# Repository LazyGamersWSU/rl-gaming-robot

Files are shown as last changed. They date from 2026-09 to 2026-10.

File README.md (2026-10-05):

# RL Gaming Robot

The RL Gaming Robot is a senior design project focused on developing a Reinforcement Learning system that learns to play games through repeated attempts and applies its learned behavior to a game to ultimately improve its score.

The current target game is Tetris. The long-term goal is for the RL agent to make gameplay decisions and output controller commands that are translated into physical actions pressed on a controller by a robotic system.

This repository contains the software and hardware elements used to create the project.

## Repository Structure

```text
RL-Gaming-Robot/

├── hardware/
│   ├── electronics/
│   ├── experiments/
│   ├── firmware/
│   ├── mechanical/
│   └── photos/
│ 
├── software/
│   ├── requirements/
│   ├── environment/
│   ├── agent/
│   └── test_cases/
│
└── README.md
```

## Hardware

The `hardware` directory contains the mechanical and electronic development files for the RL Gaming Robot.

This includes:

* Actuator experiments and testing
* CAD models and mechanical designs
* Controller mounting and interaction components
* Production hardware designs
* Hardware documentation and validation

See the [hardware README](hardware/README.md) for additional information.

## Software

The `software` directory contains the software required to develop and operate the RL system.

This includes:

* Python environment and dependency requirements
* Game environment code
* Reinforcement Learning agent code
* Software test cases

The software is responsible for interacting with the game environment, training and executing the RL agent, and producing controller actions for the hardware system.

See the [software README](software/README.md) for additional information.

## System Overview

The intended system operates as a feedback loop:

```text
┌─────────────────┐
│ Game Environment│
└────────┬────────┘
         │
         │ Game State
         ▼
┌─────────────────┐
│    RL Agent     │
└────────┬────────┘
         │
         │ Controller Action
         ▼
┌─────────────────┐
│ Robot Controller│
└────────┬────────┘
         │
         │ Physical Command
         ▼
┌─────────────────┐
│  Robotic System  │
└────────┬────────┘
         │
         │ Button Press
         ▼
┌─────────────────┐
│  NES Controller │
└────────┬────────┘
         │
         └──────────────► Game
```

The game produces a new state after each action, allowing the RL agent to continually evaluate the game and select its next action.

## Testing

Testing is an integral part of the project and is performed throughout both software and hardware development.

Software testing focuses on:

* Game-state processing
* RL agent behavior
* Action generation
* Software component integration
* Model performance and repeatability

Hardware testing focuses on:

* Actuator performance
* Button press accuracy
* Timing and reliability
* Mechanical positioning
* Hardware/software integration

Test cases are maintained within the appropriate software and hardware directories.

## Development Philosophy

The project is organized around **experimentation, validation, and integration**.

Development follows these general principles:

1. **Experiment** — Develop and test individual concepts and components.
2. **Validate** — Verify that components meet their intended requirements.
3. **Integrate** — Combine validated software and hardware components.
4. **Test** — Evaluate the complete system and identify integration issues.
5. **Iterate** — Use test results to improve the system.

Experimental implementations should be validated before being incorporated into the production system.

## Project Goals

The primary goals of the RL Gaming Robot project are to:

* Develop an RL agent capable of improving its gameplay through repeated attempts.
* Create a software environment for training and evaluating the agent.
* Develop a robotic system capable of physically interacting with a gaming controller.
* Establish reliable communication between the software and hardware systems.
* Test the performance and reliability of the complete system.
* Demonstrate the transfer of learned behavior from the software environment to physical gameplay.

## Current Development Status

The project is being developed incrementally, beginning with the software RL environment and agent before progressing toward full hardware integration.

Major development stages include:

1. Software environment development
2. RL agent development and training
3. Software testing and performance evaluation
4. Hardware development and validation
5. Software/hardware integration
6. Full-system testing
7. Final NES Tetris demonstration

## Team Roles

### Trystan Donmoyer - Software Development Lead
- Leads development of the reinforcement learning software and agent
- Develops training, inference, and game interaction systems
- Maintains the software architecture and coordinates software-side implementation

### Sam Culp - Hardware Development
- Leads hardware design and implementation of the physical gaming robot
- Designs and assembles the PCB, power distribution, actuator system, and mechanical components
- Develops and integrates Arduino firmware for hardware control and communication with the software system

### Matthew Dynes-Winberry - Integration & Testing
- Integrates the software and hardware systems into a complete working platform
- Develops and manages system-level testing and validation
- Troubleshoots issues across hardware/software interfaces and verifies system reliability

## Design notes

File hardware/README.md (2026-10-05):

# Hardware

Hardware design, firmware, schematics, experiments, and documentation for the RL gaming robot.

## Directories

* [`electronics/`](electronics/) — Electrical system documentation, PCB design, power budget, and wiring diagrams.
* [`mechanical/`](mechanical/) — Mechanical design documentation and CAD files.
* [`firmware/`](firmware/) — Arduino firmware for the hardware control system.
* [`experiments/`](experiments/) — Hardware and controller experiments used during development.
* [`photos/`](photos/) — Miscellaneous hardware photos.

## System Overview

Hardware Block Diagram

For detailed electrical architecture and subsystem documentation, see [`electronics/`](electronics/).

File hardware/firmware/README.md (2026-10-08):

# Firmware

Arduino firmware for controlling the solenoid driver PCB and translating commands received over USB into physical controller inputs.
The current code content is a demonstration of what is to come.

## Planned Contents

- Arduino source code
- Pin assignments
- Serial communication protocol
- Solenoid control logic

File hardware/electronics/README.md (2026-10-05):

# Electronics

The electronics system controls and powers the solenoid actuators used to physically operate the game controller.

## Subsystems

- [PCB](pcb/) — Solenoid driver PCB design and fabrication files with revision history
- [Power](power/power_budget.md) — Battery and system power requirements
- [Wiring](wiring/) — Electrical wiring and connections (visual)

## Signal Path

Arduino → MOSFET driver → Solenoids

## Power Path

Battery → BMS → Power switch → Fuse  → Solenoid driver PCB → Solenoids

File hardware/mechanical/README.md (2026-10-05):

# Mechanical

Mechanical components for mounting and positioning the solenoid actuators over the game controller. A .f3d file is a proprietary Autodesk Fusion 360 archive that stores a complete parametric 3D CAD design. This means that these files must be opened with Autodesk Fusion 360.

## CAD Files

- `Actuator Plate.f3d` — Mounting plate for the solenoid actuators; actuators are friction fit into sleeves
- `Gantry Support.f3d` — Frame for holding the actuator plate above the cradle 
- `SNES Cradle.f3d` — Holds the game controller in place
- `Solenoid Sleeve.f3d` — Test sleeve for positioning and guiding the solenoid
- `snes_overlay.jpg` — Controller reference image used during CAD design

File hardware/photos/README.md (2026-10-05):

# Photos

Miscellaneous photos of the various hardware components throughout different stages of development.

## Contents

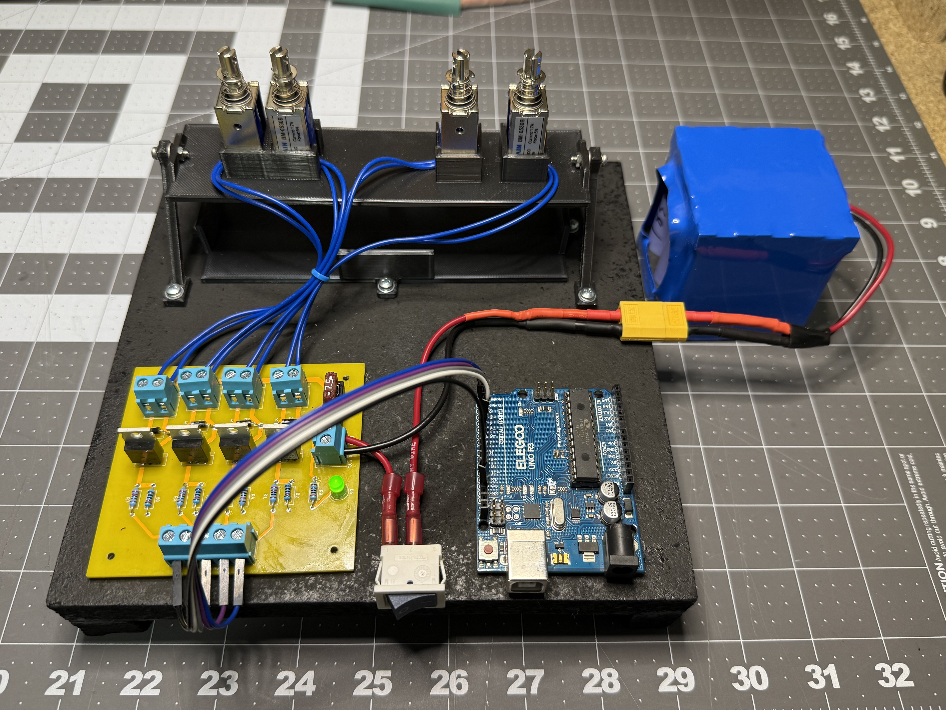
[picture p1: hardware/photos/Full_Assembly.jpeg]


Full assembly of all the components. The build plate is a piece of 1/2" particle board that was spray painted black. Bottom-left: circuit board. Bottom-right: Arduino. Top: controller cradle and actuator plate. Right: power supply and connector.

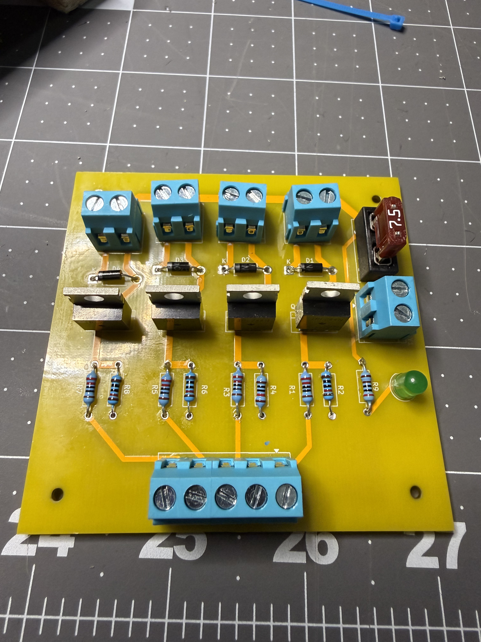
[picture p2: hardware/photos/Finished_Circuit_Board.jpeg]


Final circuit with all components soldered on. Corresponds with [revision v4.0](../electronics/pcb/PCB_REVISION_HISTORY.md). This board was designed by Sam Culp and manufactured by JLCPCB. The components were ordered from DigiKey. 

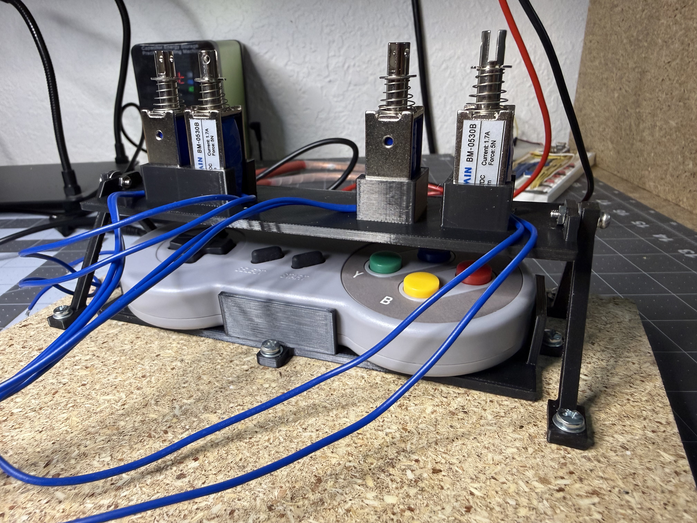
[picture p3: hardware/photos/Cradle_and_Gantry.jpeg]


SNES controller firmly held in its cradle. The gantry frame supports four solenoid linear actuators that are positioned right above the buttons.

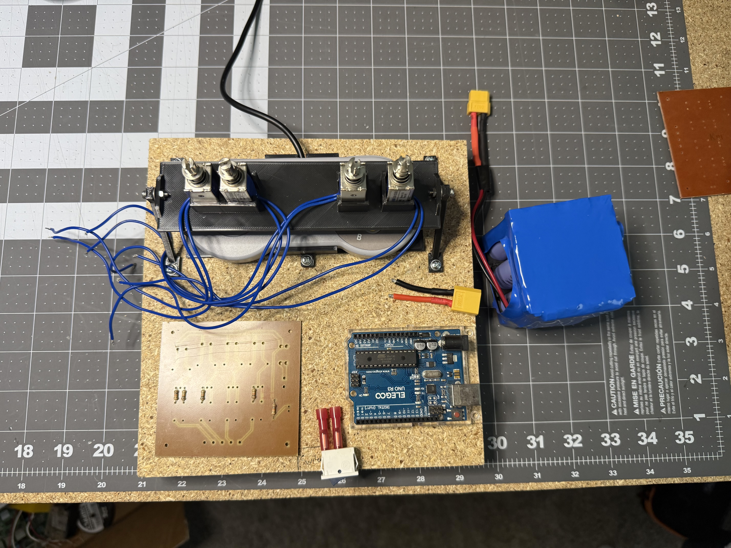
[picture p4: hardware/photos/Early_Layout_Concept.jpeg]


Initial concept for the layout of all the different components. This ended up closely resembling the final version.

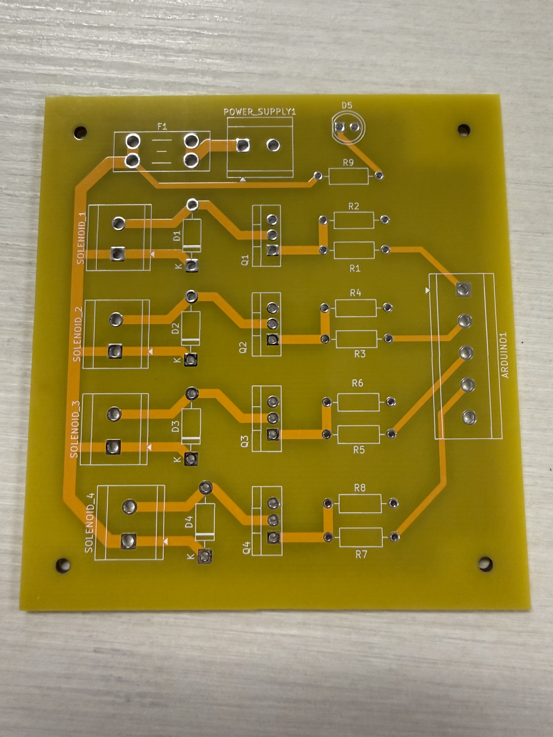
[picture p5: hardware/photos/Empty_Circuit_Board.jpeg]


Circuit board as it arrived from the manufacturer. Corresponds with [revision v4.0](../electronics/pcb/PCB_REVISION_HISTORY.md). Did not come with any components mounted, just through-holes.

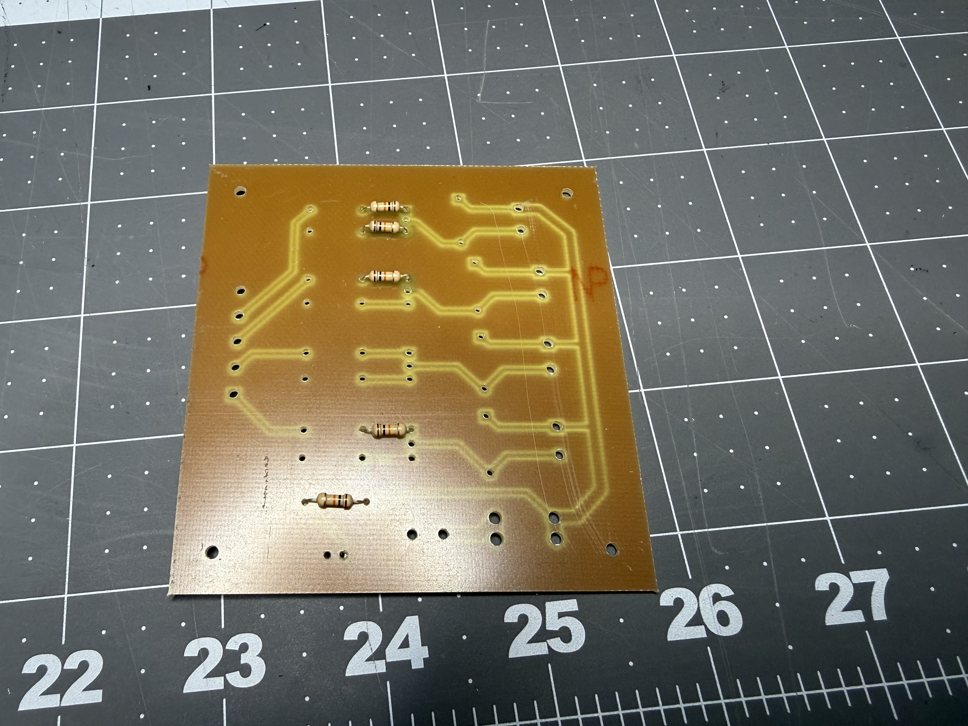
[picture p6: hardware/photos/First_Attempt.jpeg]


First attempt at manufacturing a circuit board. Corresponds with [revision v2.0](../electronics/pcb/PCB_REVISION_HISTORY.md). Sam Culp manufactured this in the Electronics Lab at Wichita State. This is a one-sided board made from a clad-copper PCB blank. Rather than laying down wires on a piece of material, the machine routed out the silhouette of each wire. Sam had to ensure proper sizing of the traces and annular rings to match the available drill bits.

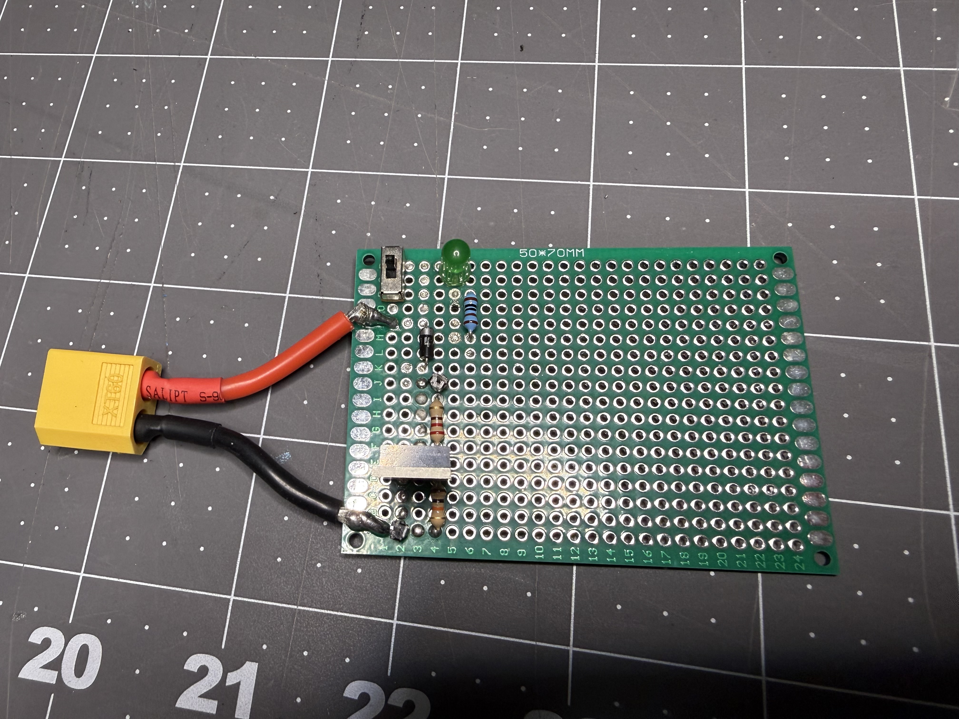
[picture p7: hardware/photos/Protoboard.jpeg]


Early proof-of-concept of the circuit soldered onto a protoboard. This board drives one actuator and takes one digital input from an arduino. The cables for the actuator were transplanted to the final build prior to this photo being taken.

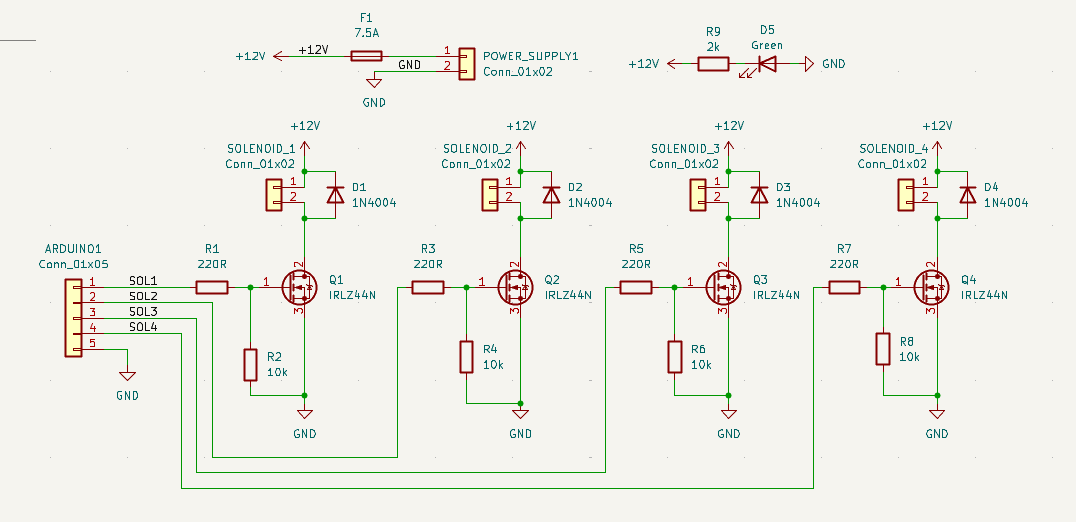
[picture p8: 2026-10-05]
hardware/electronics/wiring/schematic_diagram.png

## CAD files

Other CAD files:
hardware/mechanical/cad/Actuator Plate.f3d
hardware/mechanical/cad/Gantry Support.f3d
hardware/mechanical/cad/SNES Cradle.f3d

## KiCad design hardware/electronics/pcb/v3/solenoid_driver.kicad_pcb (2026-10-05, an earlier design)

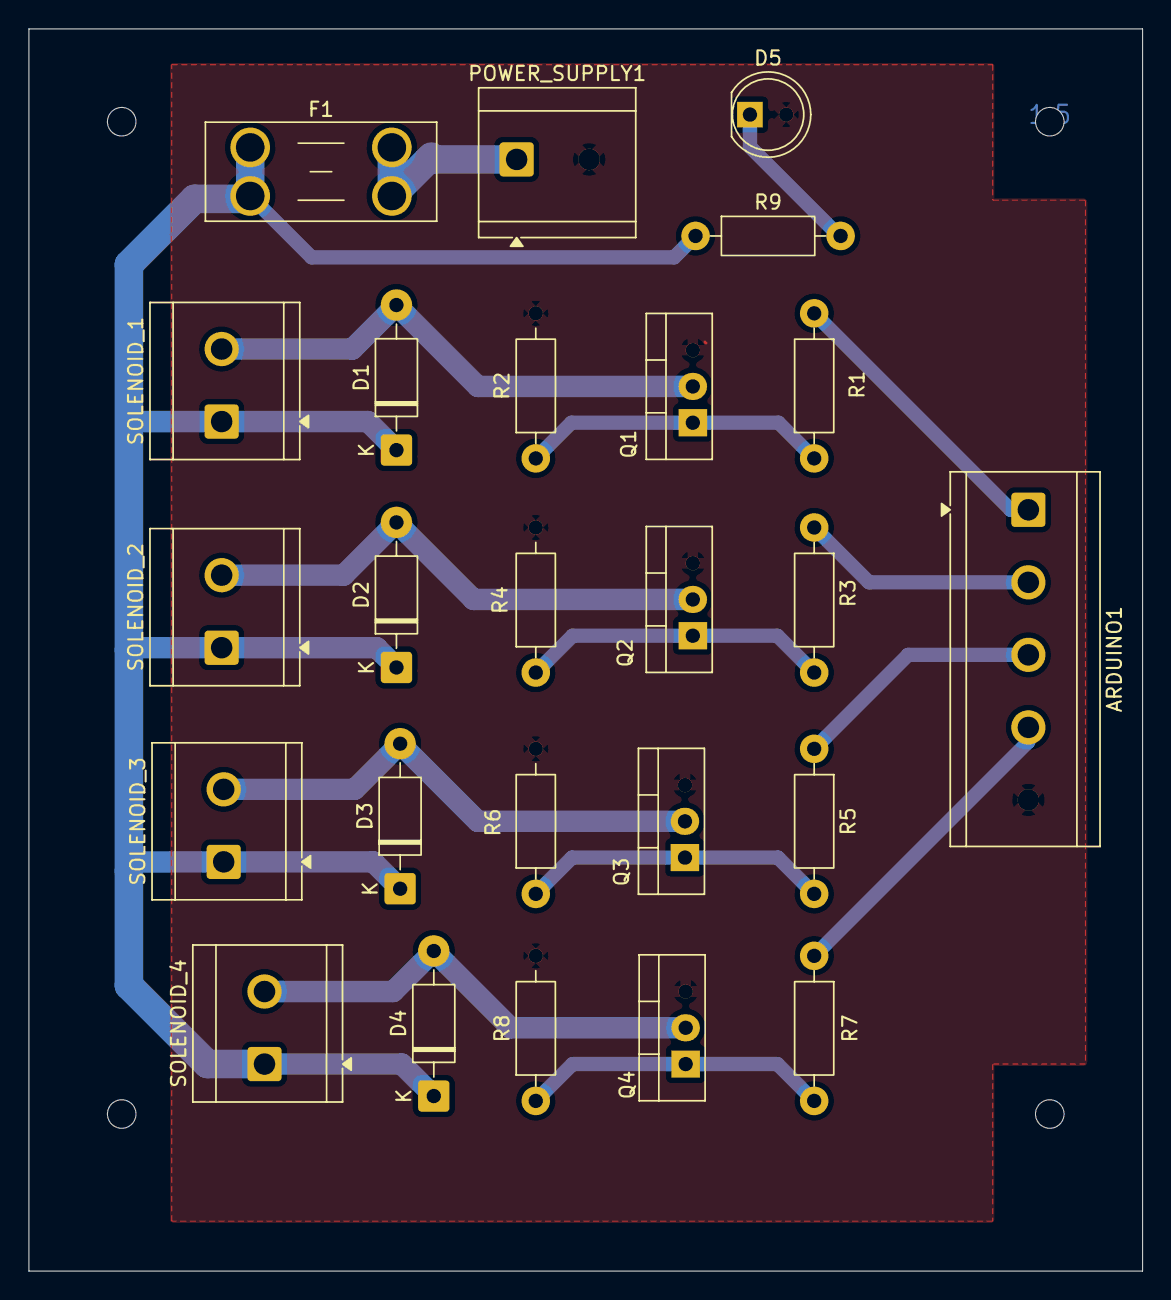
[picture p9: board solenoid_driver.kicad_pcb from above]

Board: 2 copper layers, 78.0 x 87.0 mm, 25 parts (0 on the bottom side), 16 nets.

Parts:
ARDUINO1: Conn_01x05; TerminalBlock_CUI_TB007-508-05_1x05_P5.08mm_Horizontal
D1, D2, D3, D4: 1N4004; D_DO-41_SOD81_P10.16mm_Horizontal
D5: Green; LED_D5.0mm
F1: 7.5A; Fuseholder_Blade_Mini_Keystone_3568
POWER_SUPPLY1: Conn_01x02; TerminalBlock_CUI_TB007-508-02_1x02_P5.08mm_Horizontal
Q1, Q2, Q3, Q4: IRLZ44N; TO-220-3_Vertical
R1, R3, R5, R7: 220R; R_Axial_DIN0207_L6.3mm_D2.5mm_P10.16mm_Horizontal
R2, R4, R6, R8: 10k; R_Axial_DIN0207_L6.3mm_D2.5mm_P10.16mm_Horizontal
R9: 1k; R_Axial_DIN0207_L6.3mm_D2.5mm_P10.16mm_Horizontal
SOLENOID_1, SOLENOID_2, SOLENOID_3, SOLENOID_4: Conn_01x02; TerminalBlock_CUI_TB007-508-02_1x02_P5.08mm_Horizontal

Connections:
+12V: D1.1 (K), D2.1 (K), D3.1 (K), D4.1 (K), F1.1, R9.1, SOLENOID_1.1, SOLENOID_2.1, SOLENOID_3.1, SOLENOID_4.1
/SOL1: ARDUINO1.1, R1.1
/SOL2: ARDUINO1.2, R3.1
/SOL3: ARDUINO1.3, R5.1
/SOL4: ARDUINO1.4, R7.1
GND: ARDUINO1.5, D5.2 (A), POWER_SUPPLY1.2, Q1.3 (S), Q2.3 (S), Q3.3 (S), Q4.3 (S), R2.2, R4.2, R6.2, R8.1
unnamed: D1.2 (A), Q1.2 (D), SOLENOID_1.2
unnamed: D2.2 (A), Q2.2 (D), SOLENOID_2.2
unnamed: D3.2 (A), Q3.2 (D), SOLENOID_3.2
unnamed: D4.2 (A), Q4.2 (D), SOLENOID_4.2
unnamed: D5.1 (K), R9.2
unnamed: F1.2, POWER_SUPPLY1.1
unnamed: Q1.1 (G), R1.2, R2.1
unnamed: Q2.1 (G), R3.2, R4.1
unnamed: Q3.1 (G), R5.2, R6.1
unnamed: Q4.1 (G), R7.2, R8.1

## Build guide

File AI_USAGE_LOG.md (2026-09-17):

# AI Usage & Verification Log

**Project Name:** RL Gaming Robot

---

## Overview & AI Usage Statement

### Overview & AI Usage Statement

AI tools were used throughout the project as a supplemental development resource for brainstorming, troubleshooting, and improving implementation approaches. AI-generated code and recommendations were reviewed, tested, and modified by the project team before being incorporated into the project. The team remains responsible for understanding and verifying all implemented solutions. AI was not treated as a replacement for independent research, engineering judgment, or testing.

### Responsible AI Usage

AI was used responsibly by treating its output as a starting point rather than an authoritative source. Generated code was reviewed for correctness, tested in the project environment, and modified when necessary. Project decisions and final implementations were verified by the team, and AI assistance was documented in this log to maintain transparency and accountability.

---

## Entry 1: Prototype 1 - SNES USB Controller Input Mapping Experiment

* **Date:** August 31, 2026  
* **Tool Used:** ChatGPT  
* **Associated Git Issue:** Test SNES USB controller input mapping  
* **Associated Feature Branch:** `controller-input-test`  

### Exact Prompt Submitted:

> "quick python script for testing input on this snes usb controller i just got from walmart"

### AI Output Summary & Code Generated

AI generated a Python script using the `pygame` library to:

* Detect connected USB controllers.
* Display the controller name.
* Display the number of buttons, axes, and hats detected.
* Print button press events.
* Print button release events.
* Print joystick axis movement values.
* Print D-pad or hat movement values when applicable.

The generated experiment allowed the physical SNES USB controller to be tested interactively.

### Human Testing, Verification & Results

The controller was manually tested using the generated Python experiment. The following input mappings were observed and recorded:

#### Button Mapping

| SNES Button | Input Mapping |
|---|---:|
| X | Button 0 |
| A | Button 1 |
| B | Button 2 |
| Y | Button 3 |
| Select | Button 8 |
| Start | Button 9 |

#### D-Pad Mapping

The controller D-pad was detected as two joystick axes rather than individual buttons or a joystick hat.

| Direction | Axis | Value When Pressed |
|---|---:|---:|
| Left | Axis 0 | -1 |
| Right | Axis 0 | 1 |
| Up | Axis 1 | -1 |
| Down | Axis 1 | 1 |
| Released | Axis 0 / Axis 1 | Approximately -0.01 |

### Human Review & Modifications Identified

Testing identified that the D-pad does not return exactly `0` when released. Instead, the controller reports a value of approximately `-0.01`.

Based on this result, future controller input handling should implement a dead zone rather than checking for an exact axis value of zero.

Example dead zone approach:

```python
DEADZONE = 0.5

if axis_0 < -DEADZONE:
    print("LEFT")
elif axis_0 > DEADZONE:
    print("RIGHT")

if axis_1 < -DEADZONE:
    print("UP")
elif axis_1 > DEADZONE:
    print("DOWN")
```

---

## Entry 2: CI/CD Infrastructure - Pytest Unit Test Setup

* **Date:** September 8, 2026  
* **Tool Used:** ChatGPT  
* **Associated Git Issue:** CI/CD Infrastructure & Test Logs  
* **Associated Feature Branch:** `chore/cicd-implementation`  

### Exact Prompts Submitted:

> "whats best practice for virtual environments when i have a bunch of python tests like this"

> "Record pygame as a project dependency"

> "what directory should tests go under"

> "next"

> "okay next"

> "run tests failed. said no module named pytest but install dependecies worked and pytest was included in that"

> "add this conversation about setting up pytest to this log"

### AI Output Summary & Code Generated

ChatGPT provided guidance for establishing a Python unit-testing structure suitable for CI/CD. The guidance included:

* Moving the Python virtual environment from the individual hardware experiment directory to the repository root.
* Using one project-level virtual environment rather than separate virtual environments for individual test files.
* Adding `pygame` and `pytest` as project dependencies in `requirements.txt`.
* Keeping the virtual environment out of source control through `.gitignore`.
* Creating a top-level `tests/` directory for automated unit tests.
* Renaming the hardware controller experiment so pytest would not automatically discover it as a test module.
* Separating executable controller code from importable code by placing the controller program inside a `main()` function and using an `if __name__ == "__main__":` guard.
* Creating a unit-testable `get_button_action()` function and a corresponding pytest test.
* Configuring GitHub Actions to install dependencies and execute tests on pull requests.

### Human Testing, Verification & Results

The initial pytest execution failed because the hardware controller experiment was automatically collected as a test module and attempted to access a physical controller.

After restructuring the controller experiment, pytest was able to collect and execute the unit test without requiring physical hardware.

The final local test execution successfully reported:

```text
1 passed
```

The GitHub Actions workflow was then configured to install dependencies from `requirements.txt` and execute:

```text
python -m pytest
```

An initial CI failure was traced to an empty `requirements.txt`. After adding the required dependencies:

```text
pygame
pytest
```

the GitHub Actions test job successfully passed.

### Human Review & Modifications Identified

Human review determined that the original controller experiment was an interactive hardware test rather than a unit-testable module. The code was therefore modified so importing the module does not immediately initialize the controller or terminate when no controller is connected.

The CI workflow was also verified through a pull request, confirming that the automated pytest execution can run successfully in GitHub Actions without physical controller hardware.

---

## Entry 3: CI/CD Infrastructure - Ruff Linting

* **Date:** September 9, 2026  
* **Tool Used:** ChatGPT  
* **Associated Git Issue:** CI/CD Infrastructure & Test Logs  
* **Associated Feature Branch:** `chore/cicd-implementation`

### Exact Prompts Submitted:

> "lets continue with linting"

> "all checks passed"

> "it needs to be included in the yaml right?"

### AI Output Summary & Code Generated

ChatGPT provided guidance for adding Ruff as the project's Python linting tool. The guidance included:

* Adding `ruff` to `requirements.txt` alongside `pygame` and `pytest`.
* Installing Ruff in the project virtual environment.
* Running `python -m ruff check .` locally to identify linting issues.
* Reviewing Ruff's reported issues rather than automatically applying fixes.
* Adding a GitHub Actions workflow step to execute `python -m ruff check .` so linting is automatically performed in CI on pull requests.

### Human Testing, Verification & Results

The initial local Ruff check identified four issues: two import-formatting issues and two uses of `quit()` where Ruff recommended `sys.exit()`.

The controller input module was modified to import `sys` and replace both `quit()` calls with `sys.exit()`.

Ruff was run again with:

```text
python -m ruff check .
```

## Entry 4: ALE Modification
* **Date:** September 15, 2026  
* **Tool Used:** VS Copilot  
* **Associated Git Issue:** Updating ALE.py file  
* **Associated Feature Branch:** `feature/RLAgent`

### Exact Prompts Submitted:

> "Can you add an attempt counter in the tetris game"

### AI Output Summary & Code Generated
I’ll add the attempt number to the visible game display, not just the terminal output. Since ALE’s `human` renderer does not expose a place to draw custom text, I’ll switch the display to a Pygame window that shows the Tetris frame with score and attempt information overlaid.

Read 

The current code already prints `Attempt` below the score in the terminal, but the ALE human window cannot display that custom text. I’m adding a Pygame HUD around the live frame so the attempt counter and current score are visible while the bot plays.

Generating patch (32 lines) in 

```

```

Generating patch (31 lines) in 

```

```
The HUD is now initialized once, refreshed after every environment step, and cleaned up on exit. I’m running syntax, diagnostics, and a short startup test to ensure the Pygame display works with the Atari RGB frames.

Ran terminal command: & "c:/Users/TryDo/Senior Project 2/.venv/Scripts/python.exe" -m py_compile .venv/ale.py

Checked , no problems found

Ran terminal command: $env:SDL_VIDEODRIVER='dummy'; & "c:/Users/TryDo/Senior Project 2/.venv/Scripts/python.exe" .venv/ale.py

Killed terminal

Added a visible Pygame HUD to `ale.py`.

The game window now displays:

```text
Score: 0
Attempt: 1
```

The attempt counter updates each time a new episode begins, and the score updates during gameplay.

The script compiles successfully and the HUD passed a runtime smoke test.

Made changes.

def update_game_display(observation, score, attempt, display, font):
    """Show the Atari frame with the current score and attempt counter."""
    frame = pygame.surfarray.make_surface(np.transpose(observation, (1, 0, 2)))
    frame = pygame.transform.scale(frame, (frame.get_width() * 3, frame.get_height() * 3))
    display.fill((20, 20, 20))
    display.blit(frame, (0, 0))
    score_text = font.render(f"Score: {score:.0f}", True, (255, 255, 255))
    attempt_text = font.render(f"Attempt: {attempt}", True, (255, 220, 80))
    panel_y = frame.get_height()
    display.blit(score_text, (12, panel_y + 8))
    display.blit(attempt_text, (12, panel_y + 42))
    pygame.display.flip()
    for event in pygame.event.get():
        if event.type == pygame.QUIT:
            stop_requested.set()

### Human Testing, Verification & Results
The code was saved and ran once more to confirm that all previous functions remained the same, and the code added an attempt counter. The new score and attempt counter were added to the bottom of the tetris window in readable font and color.

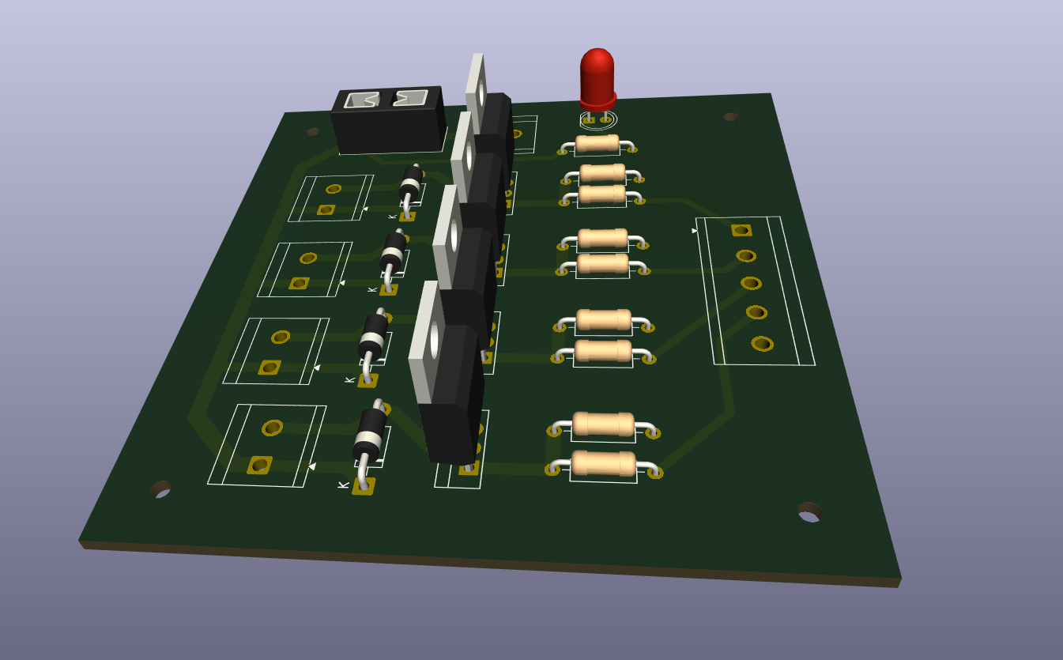
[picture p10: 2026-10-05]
hardware/electronics/wiring/pcb_3d_view.png

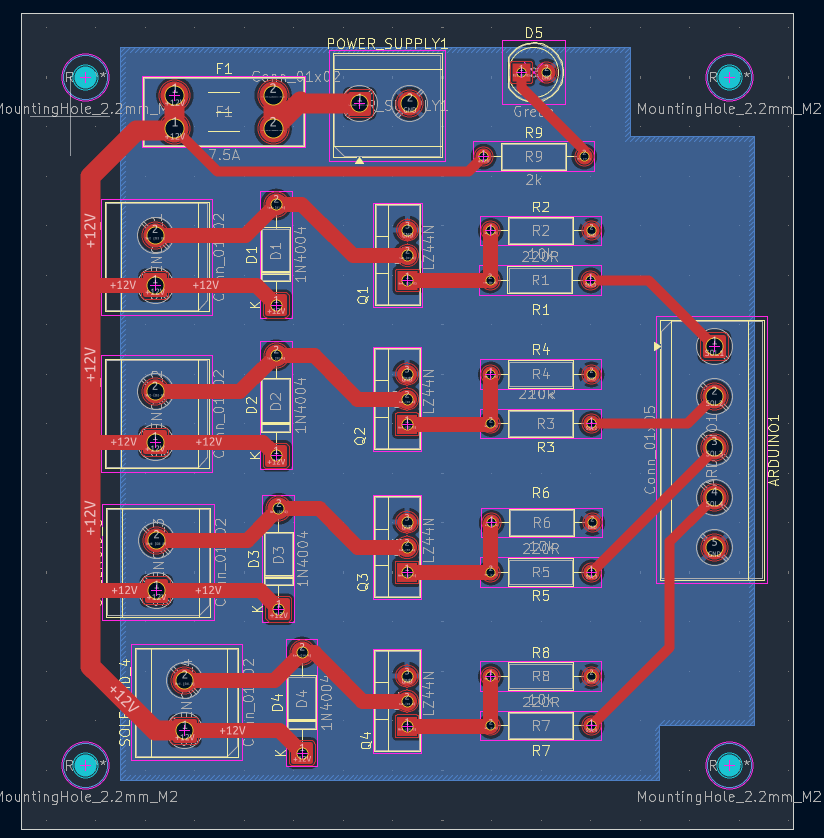
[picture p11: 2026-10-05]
hardware/electronics/wiring/pcb_diagram.png

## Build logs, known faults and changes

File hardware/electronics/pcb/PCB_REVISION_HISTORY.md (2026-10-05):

# PCB Revision History

This document tracks revisions to the RL Gaming Robot solenoid driver PCB and summarizes the changes made between each hardware revision.

## Revision History

| Revision | Status | Description |
| --- | --- | --- |
| **v1.0** | Initial Implementation | Initial implementation of the solenoid driver PCB. Established the basic circuit design for controlling the solenoids from the Arduino, including MOSFET switching, flyback protection, power distribution, and LED indicator circuitry. |
| **v2.0** | WSU Electronics Lab Revision | Modified the PCB design to support fabrication using the single-sided PCB manufacturing process available through the WSU Electronics Lab. The ground plane was removed, wire traces were moved to the bottom copper layer, and mounting/component holes were resized to match the available router bits used for PCB fabrication. |
| **v3.0** | Circuit Correction | Corrected an error in the MOSFET control circuit identified during design review. The pull-down resistors had originally been connected to the MOSFET drain pins rather than the gate pins. The resistors were moved to the gate pins so they properly hold the MOSFETs in the off state when the Arduino control signal is inactive. |
| **v4.0** | JLCPCB Fabrication Revision | Reverted to the v1 PCB layout while retaining the circuit corrections from v3. The design was restored to a standard two-layer configuration with signal traces on the top copper layer and the ground plane on the bottom copper layer, preparing the board for fabrication through JLCPCB. |

## Revision Guidelines

* Increment the PCB revision when the schematic or physical PCB design changes.
* Record the purpose and significant changes associated with each revision.
* PCB revisions refer to the physical/electrical design and are independent of software or repository versions.

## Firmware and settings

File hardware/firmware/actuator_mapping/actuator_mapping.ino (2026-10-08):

#define SOLENOID_A 2
#define SOLENOID_Y 3
#define SOLENOID_RIGHT 4
#define SOLENOID_LEFT 5

void setup() 
{
  Serial.begin(115200);

  // set pin mode for all pins
  pinMode(SOLENOID_A, OUTPUT);
  pinMode(SOLENOID_Y, OUTPUT);
  pinMode(SOLENOID_RIGHT, OUTPUT);
  pinMode(SOLENOID_LEFT, OUTPUT);

  // write all low
  digitalWrite(SOLENOID_A, LOW);
  digitalWrite(SOLENOID_Y, LOW);
  digitalWrite(SOLENOID_RIGHT, LOW);
  digitalWrite(SOLENOID_LEFT, LOW);
}

void loop() 
{
  if (Serial.available() > 0) {
    char command = Serial.read();
    pulse(command);
  }
}

void pulse(char command)
{
  switch (command)
  {
    case '1':
      Serial.println("Pulsing A...");
      digitalWrite(SOLENOID_A, HIGH);
      delay(100);
      digitalWrite(SOLENOID_A, LOW);
      break;
    case '2':
      Serial.println("Pulsing Y...");
      digitalWrite(SOLENOID_Y, HIGH);
      delay(100);
      digitalWrite(SOLENOID_Y, LOW);
      break;
    case '3':
      Serial.println("Pulsing RIGHT (D-PAD)...");
      digitalWrite(SOLENOID_RIGHT, HIGH);
      delay(100);
      digitalWrite(SOLENOID_RIGHT, LOW);
      break;
    case '4':
      Serial.println("Pulsing LEFT (D-PAD)...");
      digitalWrite(SOLENOID_LEFT, HIGH);
      delay(100);
      digitalWrite(SOLENOID_LEFT, LOW);
      break;
  }
}

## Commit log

2026-09-15 refactor: created folders for different pcb iterations
    [solenoid_driver.kicad_pcb, solenoid_driver.kicad_sch]
2026-09-15 docs: created file for tracking PCB revision history
2026-09-15 docs: filled out PCB revision history
2026-09-16 feat: created v4 pcb
    [solenoid_driver.kicad_pcb, solenoid_driver.kicad_sch]
2026-09-16 chore: remove old SNES cradle
    [SNES Cradle.f3d]
2026-09-16 fix: enlarge mount hole size on gantry and cradle
    [Gantry Support.f3d, SNES Cradle.f3d]
2026-09-16 chore: remove old actuator plate
    [Actuator Plate.f3d]
2026-09-16 fix: lengthen actuator plate
    [Actuator Plate.f3d]
2026-10-01 docs: first couple hardware photos
2026-10-01 docs: enhanced hardware READMEs
    [solenoid_driver.kicad_pcb, solenoid_driver.kicad_sch]
2026-10-01 docs: link circuit board photos to revision history
2026-10-05 Chore: Update naming and commenting
    Updated variable names and added comments to important lines.
    Removed all traces of the counter clockwise option.
    Removed recording a key release.
    Added the option to swap who was playing by pressing spacebar.
    Updated text on screen to show who is playing.
2026-10-08 Feature: Latency and Button placement
    Updated the code to simulate latency from action select and action execution.
    Also swapped button controls around to match the actuators Sam made.
